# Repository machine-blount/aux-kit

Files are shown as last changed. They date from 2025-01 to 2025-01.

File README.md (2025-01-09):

# aux-kit
***Your new auxiliary framework***

Aux-kit is designed to be an all in one auxiliary/supplementary solution for any electric-powered solar car teams competing in the National Solar Car Challenge. In its current version It is designed as a Pi-HAT which connects to multiple expansion boards for quick iteration on separate parts of the system. 

All of the boards are only double sided so if you have an iso-mill or a fiber laser you can cook yourself up an aux-kit quickly for cheap. Most of the components are common but you may have to look out for:

- CAT24C256(EEPROM)
- DMMT5401-7(PNP Transistor Pair), 
- DMG2305UX(P-Channel Enhancement Mode MOSFET), 
- LM2596(Step-Down Converter).

## v1.0.0 Feature List
- Horn Control 
- Left Turn Signals  
- Right Turn Signals
- Hazards
- Brake Lights
- Battery Monitor 
- On-Board 12V-5V Step-Down Converter

Currently aux-kit only supports the basic supplementary/auxiliary requirements for the ESPV division but this is why the board leaves you with ~35mm x 22mm of square free real estate for any additional hardware. Additionally aux-kit has solder jumpers on the underside of the board which allow you to choose whether to control certain features programmatically through the Pi directly, or if you just want the integrated analog control to handle it for you. 

Initially I had designed aux-kit for my own team but because of the collaborative environment inside of the NSCC I had second thoughts and decided to open source the project for any another team to contribute.

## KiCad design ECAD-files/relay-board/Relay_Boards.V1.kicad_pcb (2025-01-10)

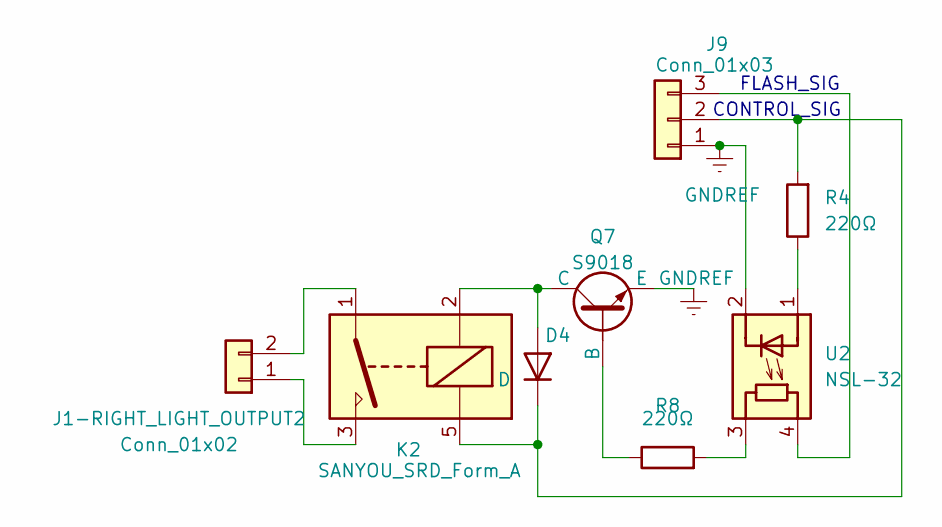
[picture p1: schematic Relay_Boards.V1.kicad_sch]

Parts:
D4: D; D_A-405_P7.62mm_Horizontal
J1-RIGHT_LIGHT_OUTPUT2: Conn_01x02; TerminalBlock_bornier-2_P5.08mm
J9: Conn_01x03; JST_XH_B3B-XH-A_1x03_P2.50mm_Vertical
K2: SANYOU_SRD_Form_A; Relay_SPDT_SANYOU_SRD_Series_Form_C
Q7: S9018; PinHeader_1x03_P2.54mm_Vertical
R4, R8: 220Ω; R_Axial_DIN0207_L6.3mm_D2.5mm_P10.16mm_Horizontal
U2: NSL-32; Diode_Bridge_DIP-4_W5.08mm_P2.54mm

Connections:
GNDREF: J9.1, Q7.3 (E), U2.2 (K)
unnamed: D4.2 (A), K2.2, Q7.1 (C)
unnamed: D4.1 (K), J9.2, K2.5, R4.2
unnamed: J1-RIGHT_LIGHT_OUTPUT2.1, K2.3
unnamed: J1-RIGHT_LIGHT_OUTPUT2.2, K2.1
unnamed: J9.3, U2.4 (R)
unnamed: Q7.2 (B), R8.1
unnamed: R8.2, U2.3 (R)
unnamed: R4.1, U2.1 (A)

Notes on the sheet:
FLASH_SIG
CONTROL_SIG

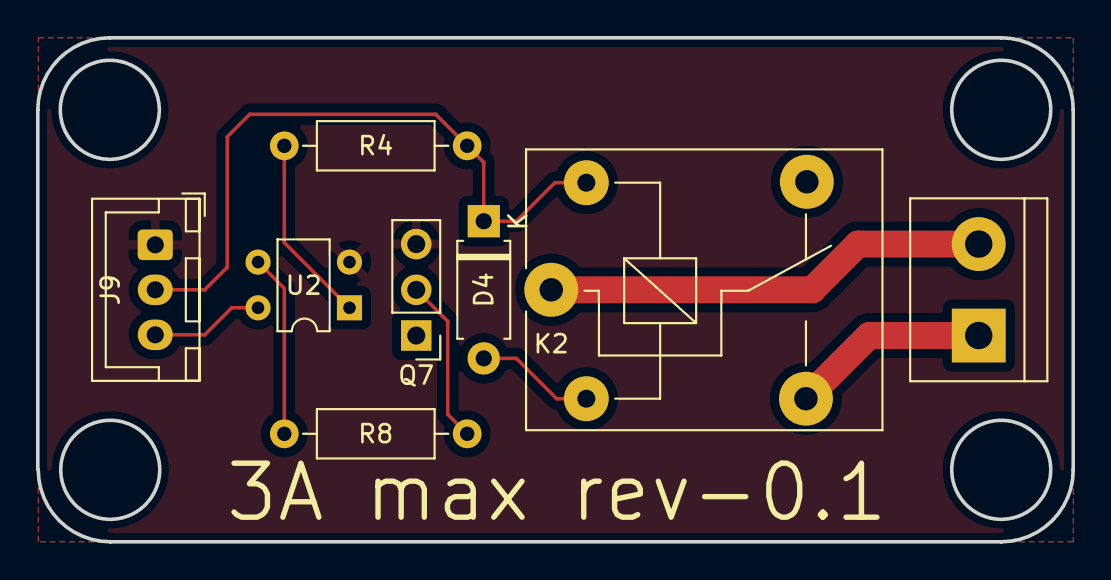
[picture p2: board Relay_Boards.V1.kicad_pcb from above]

Board: 2 copper layers, 57.5 x 28.0 mm, 8 parts (0 on the bottom side), 9 nets.

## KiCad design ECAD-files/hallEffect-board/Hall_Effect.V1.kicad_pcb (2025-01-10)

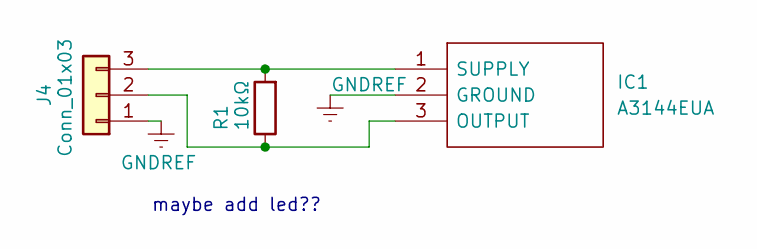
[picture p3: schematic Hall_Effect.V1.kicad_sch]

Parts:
IC1: A3144EUA; PinHeader_1x03_P1.27mm_Vertical; Manufacturer_Part_Number A3144EUA
J4: Conn_01x03; JST_XH_B3B-XH-A_1x03_P2.50mm_Vertical
R1: 10kΩ; R_Axial_DIN0207_L6.3mm_D2.5mm_P10.16mm_Horizontal

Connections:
GNDREF: IC1.2 (GROUND), J4.1
unnamed: IC1.3 (OUTPUT), J4.2, R1.1
unnamed: IC1.1 (SUPPLY), J4.3, R1.2

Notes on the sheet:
maybe add led??

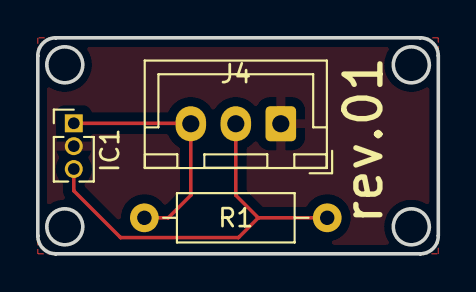
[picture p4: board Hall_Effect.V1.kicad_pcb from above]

Board: 2 copper layers, 22.2 x 12.0 mm, 3 parts (0 on the bottom side), 3 nets.

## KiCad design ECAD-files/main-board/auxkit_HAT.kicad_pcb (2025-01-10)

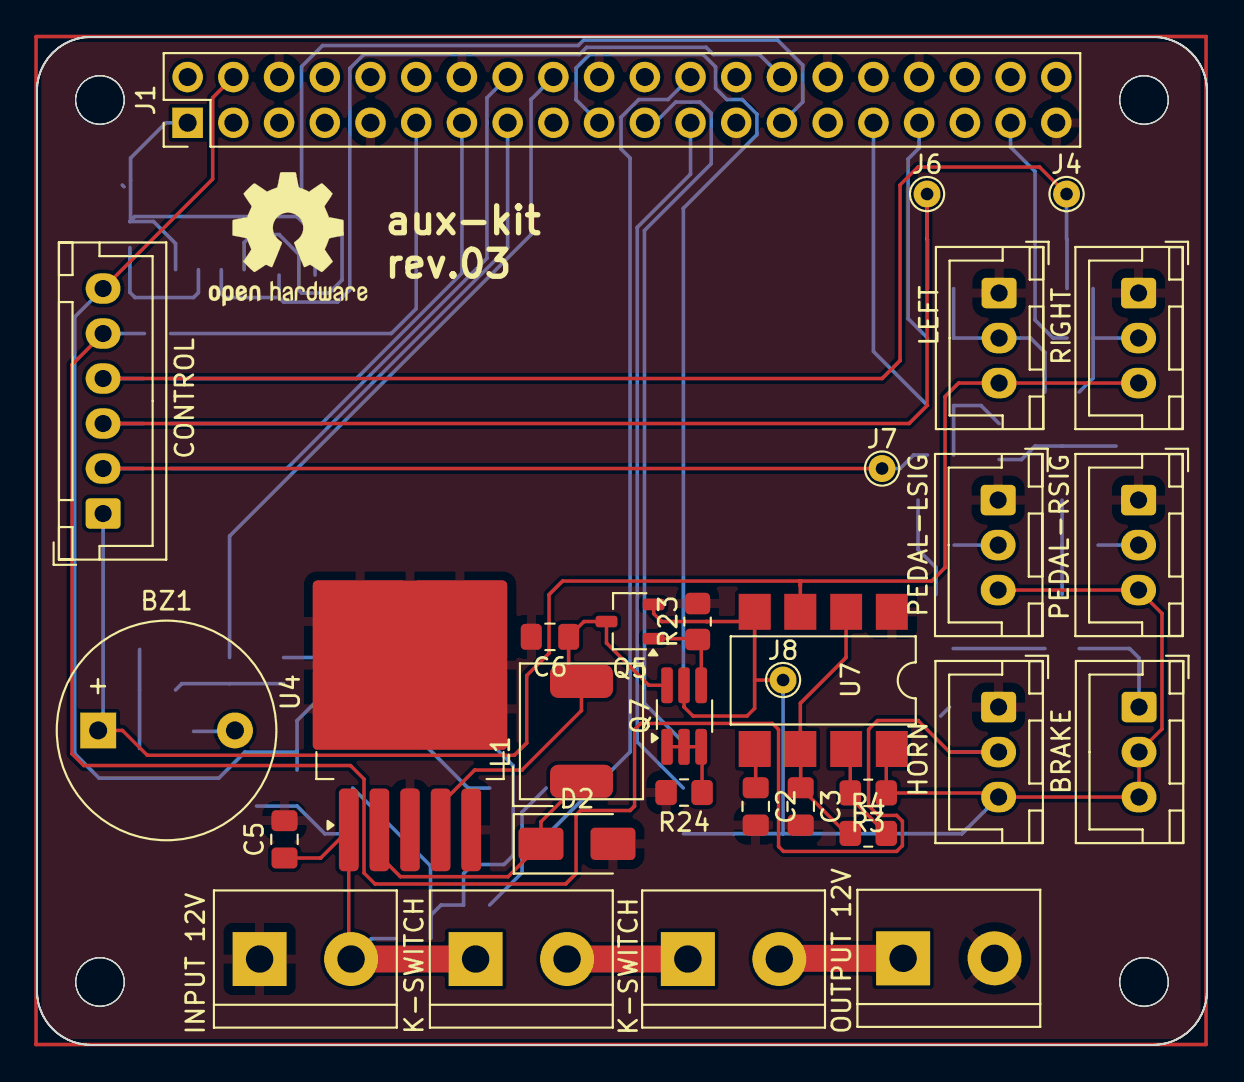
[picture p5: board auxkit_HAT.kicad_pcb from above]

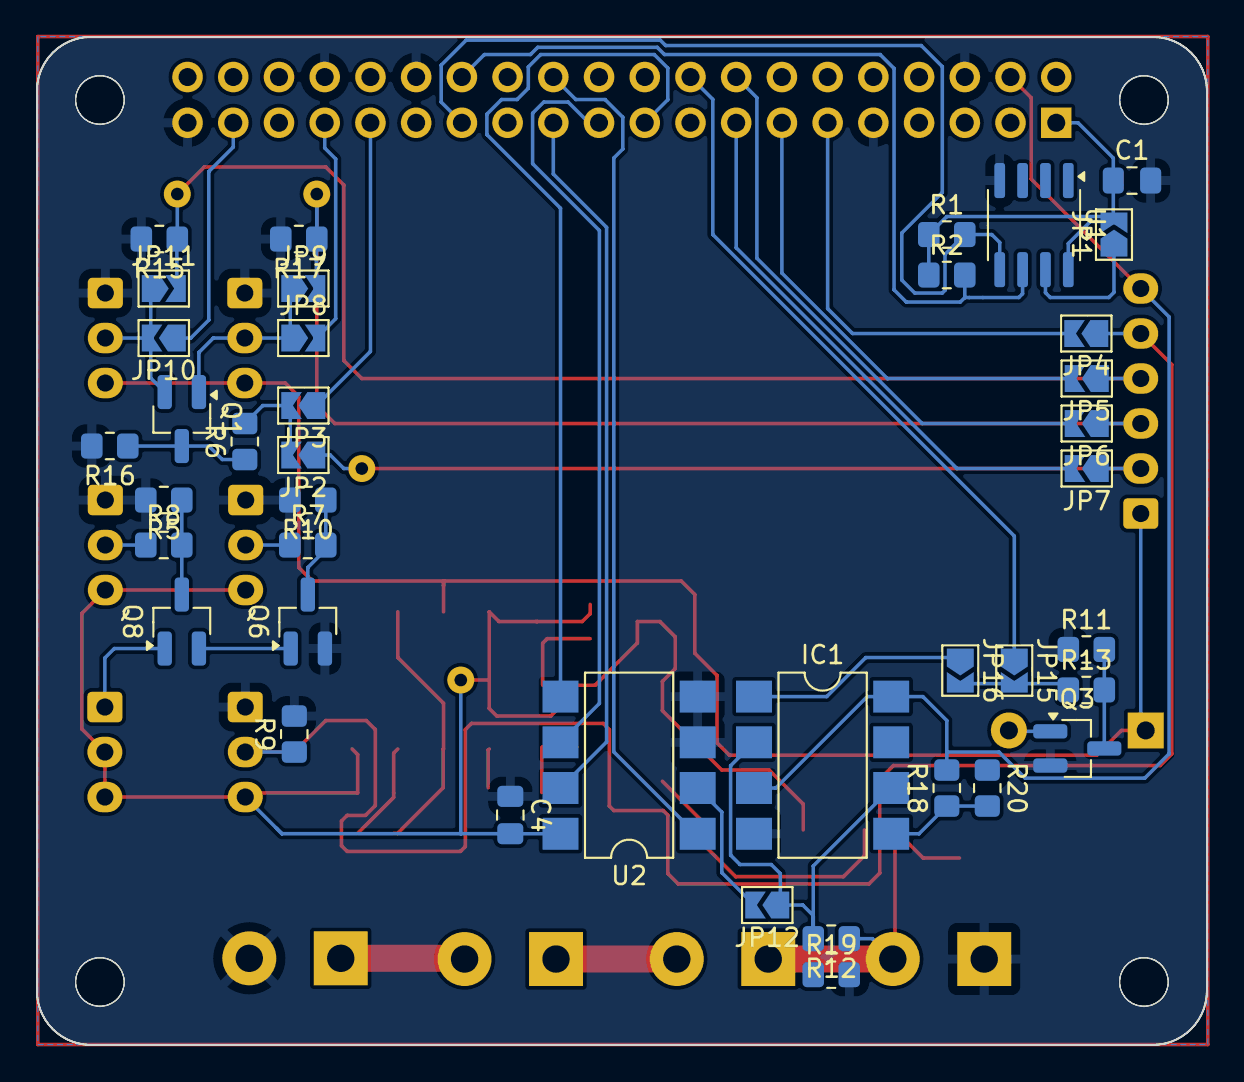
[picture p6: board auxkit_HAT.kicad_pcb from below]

Board: 2 copper layers, 65.0 x 56.0 mm, 79 parts (40 on the bottom side), 51 nets.

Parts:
BRAKE: BRAKE_LIGHT; JST_XH_B3B-XH-A_1x03_P2.50mm_Vertical
BZ1: Buzzer; Buzzer_12x9.5RM7.6
C1: 100n; C_0805_2012Metric_Pad1.18x1.45mm_HandSolder
C2, C4: 0.1µF; C_0805_2012Metric_Pad1.18x1.45mm_HandSolder
C3: 1µF; C_0805_2012Metric_Pad1.18x1.45mm_HandSolder
C5: 680uF; C_0805_2012Metric_Pad1.18x1.45mm_HandSolder
C6: 330uF; C_0805_2012Metric_Pad1.18x1.45mm_HandSolder
CONTROL: DRIVER_CNTRL; JST_XH_B6B-XH-A_1x06_P2.50mm_Vertical
D2: SS34; D_SMA
HORN: HORN; JST_XH_B3B-XH-A_1x03_P2.50mm_Vertical
IC1: LM393N; SMDIP-8_W7.62mm
INPUT 12V: Conn_01x02; TerminalBlock_bornier-2_P5.08mm
J1: GPIO; PinHeader_2x20_P2.54mm_Vertical
J4, J6, J7, J8: Conn_01x01; TestPoint_THTPad_D1.5mm_Drill0.7mm
JP1: ID_WP; SolderJumper-2_P1.3mm_Open_TrianglePad1.0x1.5mm
JP2, JP3, JP4, JP5, JP6, JP7, JP8, JP9, JP10, JP11, JP12, JP15, JP16: SolderJumper_2_Open; SolderJumper-2_P1.3mm_Open_TrianglePad1.0x1.5mm
K-SWITCH: Conn_01x02; TerminalBlock_bornier-2_P5.08mm
K-SWITCH#2: Conn_01x02; TerminalBlock_bornier-2_P5.08mm
L1: 33uH; L_AVX_LMLP07A7
LEFT: LEFT_TURN; JST_XH_B3B-XH-A_1x03_P2.50mm_Vertical
MH1, MH1#2, MH2, MH2#2, MH3, MH3#2, MH4, MH4#2: MountingHole_2.7mm_M2.5
OUTPUT 12V: Conn_01x02; TerminalBlock_bornier-2_P5.08mm
PEDAL-LSIG: LEFT_TURN; JST_XH_B3B-XH-A_1x03_P2.50mm_Vertical
PEDAL-RSIG: RIGHT_TURN; JST_XH_B3B-XH-A_1x03_P2.50mm_Vertical
Q1, Q3, Q6, Q8: NPN; SOT-23_Handsoldering
Q5: DMG2305UX; TSOT-23
Q7: DMMT5401-7; TSOT-23-6_HandSoldering
R1, R2: 3.9k; R_0805_2012Metric_Pad1.20x1.40mm_HandSolder
R3: ?Ω; R_0805_2012Metric_Pad1.20x1.40mm_HandSolder
R4: 1kΩ; R_0805_2012Metric_Pad1.20x1.40mm_HandSolder
R5, R10: 4.7kΩ; R_0805_2012Metric_Pad1.20x1.40mm_HandSolder
R6, R7, R8, R9, R11, R13, R15, R16, R17: R; R_0805_2012Metric_Pad1.20x1.40mm_HandSolder
R12: 6.8K; R_0805_2012Metric_Pad1.20x1.40mm_HandSolder
R18: 220Ω; R_0805_2012Metric_Pad1.20x1.40mm_HandSolder
R19: 4.7K; R_0805_2012Metric_Pad1.20x1.40mm_HandSolder
R20: 2.2K; R_0805_2012Metric_Pad1.20x1.40mm_HandSolder
R23: 47K; R_0805_2012Metric_Pad1.20x1.40mm_HandSolder
R24: 10K; R_0805_2012Metric_Pad1.20x1.40mm_HandSolder
RIGHT: RIGHT_TURN; JST_XH_B3B-XH-A_1x03_P2.50mm_Vertical
U1: CAT24C256; SOIC-8_3.9x4.9mm_P1.27mm
U2: MCP3002; SMDIP-8_W7.62mm
U4: LM2596S-5; TO-263-5_TabPin3
U7: NE555P; SMDIP-8_W7.62mm

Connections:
+3V3: C1.1, J1.1, J1.17, JP1.2 (B), R1.1, R2.1, U1.8 (VCC)
+5V: BRAKE.2, BRAKE.3, C4.2, CONTROL.6, HORN.3, IC1.3 (IN1(+)), IC1.8 (VCC), J1.4, J8.1, PEDAL-LSIG.3, PEDAL-RSIG.3, Q5.2 (S), Q7.5 (E2), R3.1, R18.2, U2.8 (VDD/VREF), U7.4 (R), U7.8 (VCC)
/ANO_ALARM: IC1.1 (OUTPUT1), JP16.1 (A)
/DIGI-ALARM24: J1.18, JP15.1 (A)
/FLASH_GEN: BZ1.1 (+), CONTROL.1, LEFT.3, RIGHT.3, U7.3 (Q)
/GPIO8/SPI0.CE0: J1.24, U2.1 (~CS/SHDN)
/GPIO9/SPI0.MISO: J1.21, U2.6 (DOUT)
/GPIO10/SPI0.MOSI: J1.19, U2.5 (DIN)
/GPIO11/SPI0.SCLK: J1.23, U2.7 (CLK)
/HAZARD-GPIO23: J1.15, JP7.1 (A)
/HAZARD-SIG6: J1.31, JP3.1 (A)
/HAZARD_CNTRL: CONTROL.2, J7.1, JP2.1 (A), JP7.2 (B)
/HORN-CTRL: HORN.2, R9.1
/HORN-GPIO17: J1.11, JP4.2 (B)
/HORN_CTRL: CONTROL.5, JP4.1 (A)
/ID_SCL: J1.28, R2.2, U1.6 (SCL)
/ID_SDA: J1.27, R1.2, U1.5 (SDA)
/LEFT-GPIO22: J1.16, JP6.2 (B)
/LEFT-SIG13: J1.33, JP8.2 (B)
/LEFT_CNTRL: CONTROL.3, J6.1, JP6.1 (A), JP9.2 (B), R17.1
/LEFT_PEDAL_SENSOR: Q6.2 (B), R7.1, R10.1
/RIGHT-GPIO27: J1.13, JP5.2 (B)
/RIGHT-SIG26: J1.37, JP10.1 (A)
/RIGHT_CNTRL: CONTROL.4, J4.1, JP5.1 (A), JP11.2 (B), R15.1
/RIGHT_PEDAL_SENSOR: Q8.2 (B), R5.1, R8.2
/~4.5: IC1.5 (IN2(+)), R18.1, R20.2
GNDREF: C1.2, C2.2, C3.2, C4.1, C5.2, C6.2, D2.2 (A), HORN.1, IC1.4 (GND), INPUT 12V.1, J1.6, J1.9, J1.14, J1.20, J1.25, J1.30, J1.34, J1.39, LEFT.1, OUTPUT 12V.1, PEDAL-LSIG.1, PEDAL-RSIG.1, Q3.3 (E), Q6.3 (E), R5.2, R9.2, R10.2, R11.1, R15.2, R16.2, R17.2, R19.2, R20.1, R23.2, R24.2, RIGHT.1, U1.4 (GND), U2.3 (CH1), U2.4 (VSS), U4.3 (GND), U4.5 (~ON/OFF), U7.1 (GND)
unnamed: BZ1.2 (-), Q3.1 (C)
unnamed: D2.1 (K), L1.1, U4.2 (OUT)
unnamed: IC1.2 (IN1(-)), IC1.6 (IN2(-)), JP12.1 (A), R12.2, R19.1
unnamed: C5.1, INPUT 12V.2, K-SWITCH#2.1, R12.1, U4.1 (VIN)
unnamed: K-SWITCH.2, OUTPUT 12V.2
unnamed: BRAKE.1, Q8.1 (C)
unnamed: JP8.1 (A), JP9.1 (A), LEFT.2, Q1.1 (C)
unnamed: JP10.2 (B), JP11.1 (A), Q1.3 (E), RIGHT.2
unnamed: PEDAL-RSIG.2, R8.1
unnamed: PEDAL-LSIG.2, R7.2
unnamed: JP1.1 (A), U1.7 (WP)
unnamed: JP2.2 (B), JP3.2 (B), R6.2
unnamed: JP12.2 (B), U2.2 (CH0)
unnamed: JP15.2 (B), JP16.2 (B), R13.1
unnamed: K-SWITCH.1, K-SWITCH#2.2
unnamed: Q1.2 (B), R6.1, R16.1
unnamed: Q3.2 (B), R11.2, R13.2
unnamed: C6.1, L1.2, Q5.3 (D), Q7.6 (E1), U4.4 (FB)
unnamed: Q5.1 (G), Q7.4 (C2), R23.1
unnamed: Q6.1 (C), Q8.3 (E)
unnamed: Q7.1 (C1), Q7.2 (B1), Q7.3 (B2), R24.1
unnamed: C2.1, U7.5 (CV)
unnamed: R3.2, R4.2, U7.7 (DIS)
unnamed: C3.1, R4.1, U7.2 (TR), U7.6 (THR)
